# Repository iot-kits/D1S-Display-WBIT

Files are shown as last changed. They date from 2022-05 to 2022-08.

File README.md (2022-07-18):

# D1S-Display-WBIT
These instructions are for the Remote Display kit for users without an IoT Kits weather station. The microcontroller is preprogrammed! IF YOU REPROGRAM IT, THESE INSTRUCTIONS WILL NOT WORK.

## Assembly and Configuration Instructions
### Features:
*	Obtains localized weather information from WeatherBit.io
*	Shows current conditions and daily maximum/minimum
*	Includes wind speed and direction, precipitation type, probability and amount, pressure, temperature, humidity, cloud cover
*	Built in sensor for indoor temperature and humidity
*	User can choose metric and imperial units
*	Precise time provided by National Institute of Standards and Technology (NIST)
*	Displays Universal Coordinated Time (UTC) and your local time.
*	Daylight saving time is automatically determined
*	Almanac for local sunrise and sunset times and moon phase
### What you will need:
1.	Open a free WeatherBit account.
    *	Go to https://www.weatherbit.io/. Click the *Sign up* button, choose a username and password. Write them down! After a few minutes WeatherBit will e-mail a link to confirm your credentials.
    * Log in to WeatherBit. Fill out the form on the *Welcome to WeatherBit* page. The objective is to receive a free Application Programming Interface (API) key. For *API Tier* select “Free (Limited) | $0/mo”. For *API Usage Purpose* choose “Personal Use”. 
    *	WeatherBit will send an e-mail with your API key. You can also find your key on the Dashboard page. Record the API key.
    *	NOTE: YOU CANNOT CONFIGURE THE DISPLAY UNLESS YOU HAVE THE API KEY. It may take a few minutes for WeatherBit to provision your account. Wait for it! 
2.	Find your latitude and longitude. 
    * The weather station uses the location only to localize the weather and find the time zone.
    *	Use https://www.latlong.net/ or a similar service.
    *	The coordinates must be in decimal degrees. For example, the coordinates for the Washington Monument are latitude 39.485279, longitude -77.619972. Two decimal places are adequate: 39.49, -77.62.
    *	Note that north latitude is positive, south latitude is negative, east longitude is positive, west longitude is negative.
3.	Tools needed: 
    *	Soldering iron
    *	Rosin-core solder
    *	Diagonal cutters 
    *	Hot-melt glue gun
    *	Standard USB 5-volt adapter or power supply.
    *	Micro USB cable. Dollar store varieties are acceptable.
 
### Assemble the kit.
**[Click on any thumbnail to enlarge the photograph.]**
1. Have an activated WeatherBit account and API key as described above.
2. Lay out the parts on a safe working surface.
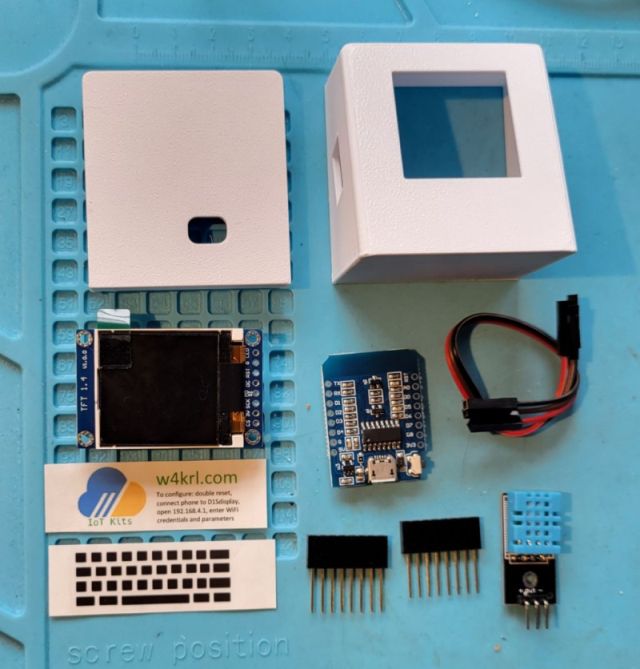
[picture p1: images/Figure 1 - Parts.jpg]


**The next few instructons use the preinstalled pins of the display unit as a fixture to align the D1 Mini assembly. Carefully follow these instructions. You will install and remove connectors several times.**

3. Place the two long-tailed sockets on the display unit pins. You will not need the short tail sockets or header pins if the are provided in the kit.
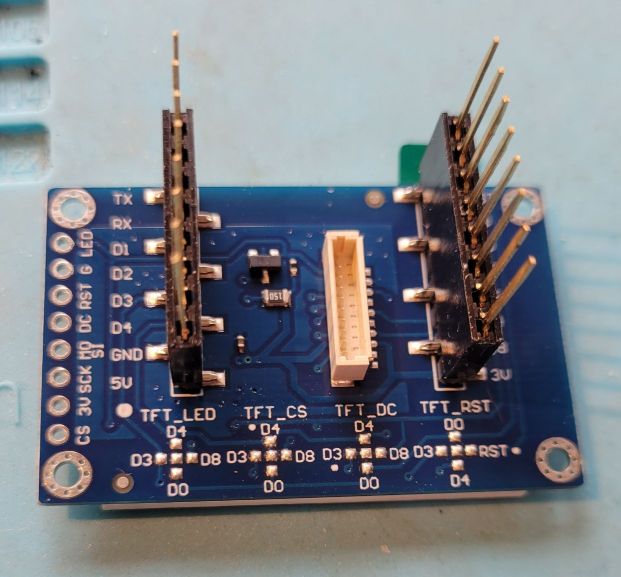
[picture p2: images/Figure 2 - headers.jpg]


4.	Carefully set the D1 Mini onto the pins with the silver case toward the back of the display unit. With the D1 Mini in the correct orientation, you will be soldering on the side with the USB connector.
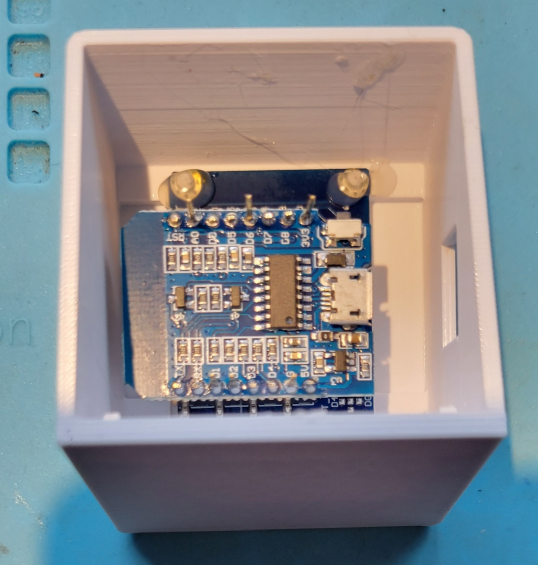
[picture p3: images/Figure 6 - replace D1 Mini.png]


5. Solder each header pin onto the D1 Mini. Carefully inspect your solder joints. Congratulations, you are done soldering.
6. Remove the D1 Mini from the display unit and set aside.
7.	Remove the protective film from the display screen. Place the display into the case with the row of pins RST, A0, D0… toward the top. Engage the holes in the display board with the molded bosses of the case.
8.	While pressing the display into the case to keep it flush, place a dab of hot melt glue on each boss. Hot melt is a good choice because it is removable. You can use other glues at your risk.
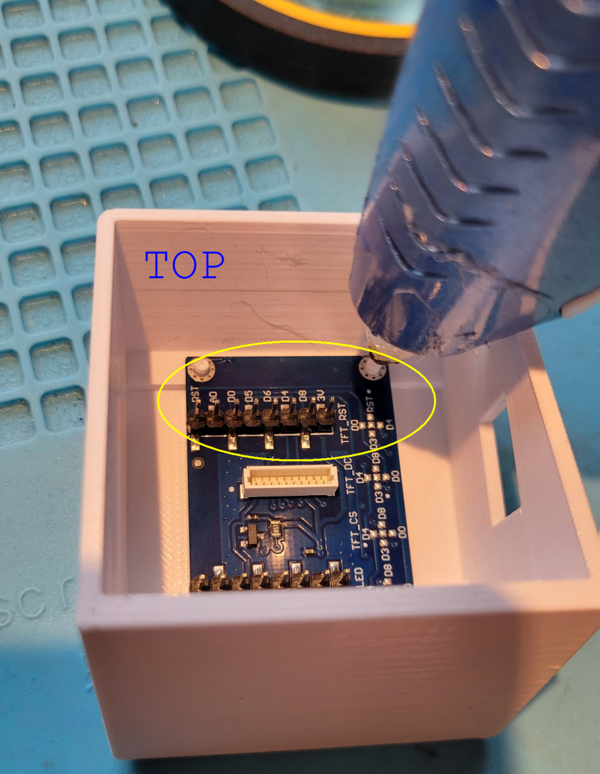
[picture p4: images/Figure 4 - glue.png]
 

9.	Cut off selected leads from the D1 Mini with diagonal cutters.   
   __MAKE SURE YOU UNDERSTAND THIS STEP BEFORE YOU CUT!__  
    *	Cut these pins: RST, D0, D5, D7, D8, TX, RX, D3, D4, 5V.  
    *	**DO NOT CUT THESE PINS:** D6, 3V3, G, D1, D2, A0.
    * NOTE: D6 is used for a DHT11 sensor if supplied. D1 and D2 are for I2C sensors such as the AHT10. A0 is an analog input not used in this kit. 
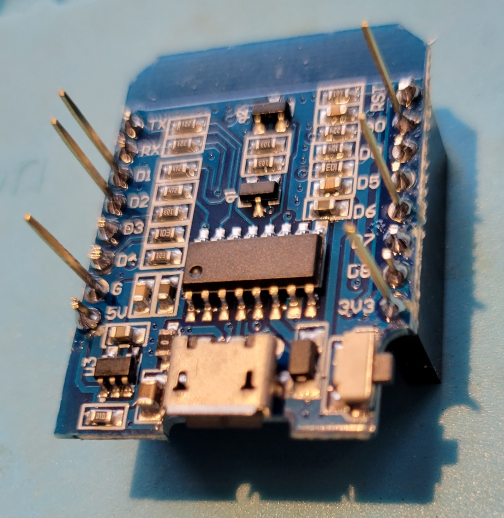
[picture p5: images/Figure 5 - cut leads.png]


10.	Replace the D1 Mini onto the back of the display unit. Observe the orientation so that pin RST of the D1 Mini engages with RST on the display board. All the pins must match.  
  __THE CORRECT ORIENTATION IS CRUCIAL!__  
  __DOUBLE CHECK THAT ALL PINS ARE CORRECTLY MATED WITH RST TO RST AND 5V to 5V, ETC.__  
    * The USB connector will line up with the hole on the side of the case.
11. The kit may be supplied with either a DHT11 or AHT10 temperature/humiidity sensor. The DHT10 has a proprietary bus using three connections. The AHT10 is an I2C device using four pins. Make the connections using the appropriate table in step 12. Place the leads of the jumper cable onto the  sensor pins. Record the color of each wire. The wire colors are different in each kit. As an optional step, you may place a small blob of hot melt glue over the plastic part of the connectors to maintain their orientation if ever removed. Do not place any glue on the metal spring portion of the connectors. Rotate the connector as needed.
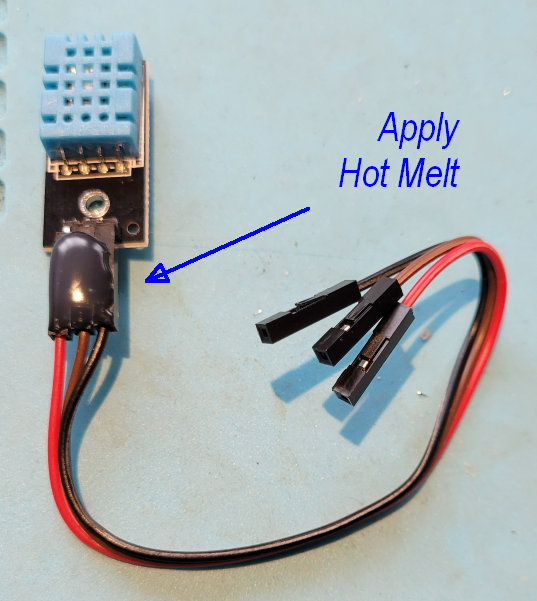
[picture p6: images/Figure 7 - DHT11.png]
  

12. Plug a Micro USB cable onto the D1 Mini USB connector through the opening in the side of the case. Feed the jumper cable through the oval slot in the rear case. Connect the jumper wires to the D1 Mini as shown in the table. If the connector is loose, try rotating it 90 degrees on the pin.

**Connections for DHT11 (if supplied)**
|DHT11 |D1 Mini|Your Wire Color|
|:----:|:-----:|:---:|
| + | 3V3 | |
| OUT  | D6 | |
| - | G | |

**Connections for AHT10 (if supplied)**
|AHT10|D1 Mini|Your Wire Color|
|:----:|:-----:|:---:|
| VIN  | 3V3 | |
| GND  | G | |
| SCL  | D1 | |
| SDA  | D2 | |

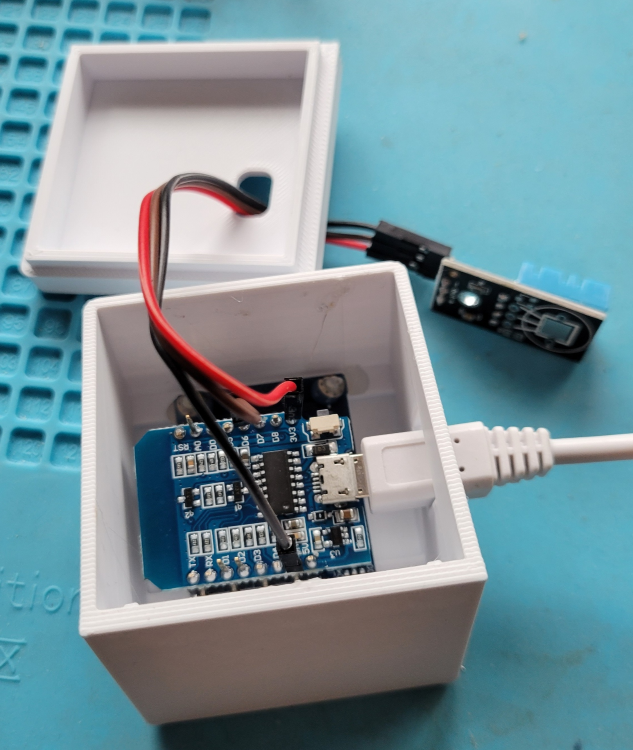
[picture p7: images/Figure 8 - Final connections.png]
 

13. Snap the rear cover onto the case. Place a dab of hot melt glue on the underside of the DHT11 sensor and place it on the upper right of the case cover.
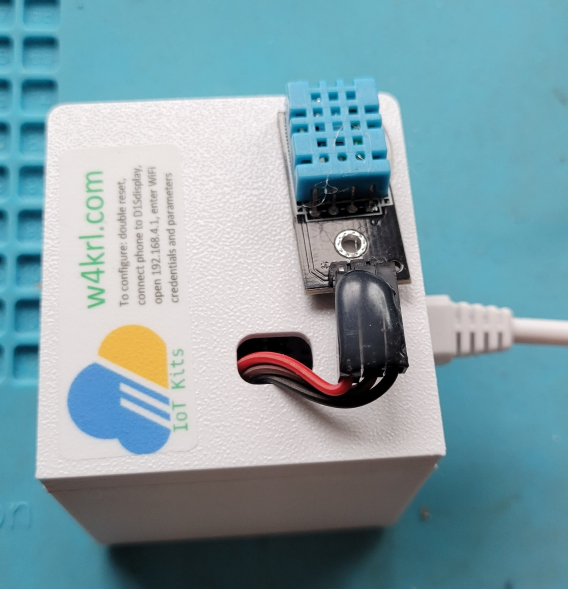
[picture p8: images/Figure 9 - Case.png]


14. Apply the nameplate on the rear of the case. The step is optional: Apply the decorative keyboard label under the display.
15. The assembly is complete. The next step is to configure the soaftware.

### Software Configuration
These instructions are for a cell phone with Wi-Fi capability. The same method could be used with a Wi Fi connected computer. 
You must be familiar with how to open the Wi-Fi connection settings on your phone, how to open your phone’s web browser, and how to enter an URL into the browser’s address bar.
This procedure will temporarily turn the weather display into a Wi-Fi access point. You will connect your cell phone to the display unit’s Wi-Fi signal. Then use your cell phone’s Internet browser to open a web page hosted by the weather display. After you enter the configuration information into the web page, the weather display will connect to your Wi-Fi network and begin normal operation.  
**Do not connect the display to a power supply until instructed to do so.**
You will need ALL the accounts and information noted in the section "What you will need" above. Do not proceed unless you have ALL this information. 
1.	Have all the configuration information at hand ready to enter:  
    *	Your Wi-Fi name (SSID) and password
    *	Your WeatherBit API key
    *	Your latitude and longitude in decimal degrees
2.	Plug the USB cable into a standard 5-volt adapter or power supply. The display will show a splash screen then brief instructions for configuring the unit will appear.
3.	Open your phone’s Wi-Fi connection settings. Turn off auoto reconnect on your current Wi-Fi connection. After a brief delay *D1Sdisplay* will appear in the list of available networks. Select it and wait for your phone to connect. You may safely ignore any warning that no Internet is available.
4.	Open your phone’s browser. Enter **192.168.4.1** into the address bar. A web page will appear.
5.	Enter the following information:  
    * Your Wi-Fi SSID (you may select this from the available networks shown at the top of the web page)
    *	Your Wi-Fi password
    * Your latitude in decimal degrees. Positive for north latitudes, negative for south latitudes.
    *	Your longitude in decimal degrees. Positive for east longitudes, negative for west longitudes.
    *	Select Imperial or Metric units.
    *	~~Check the Show clock box if you wish to have the unit display local and UTC times.~~
    *	Select the duration of each display screen: 5, 7, 10, 12, or 15 seconds. Recommendation is 7 or 10 seconds.
6.	The weather display will save the configuration data, connect to your WI-Fi and begin downloading time and weather information.  This may take a minute or so.
7.	Go back to your phone settings and turn on auto reconnect for your regular Wi-Fi connection.
8.	If you ever need to change any parameter, press the reset button on the D1 Mini twice in succession. You may have to do this a few times. The unit goes into configuration mode when the blue LED on the D1 Mini turns on and the configuration reminder screen appears.
9. See [Display Descriptions](https://github.com/iot-kits/D1S-Display-WBIT/blob/main/DISPLAY_DESCRIPTIONS.md) for more information.

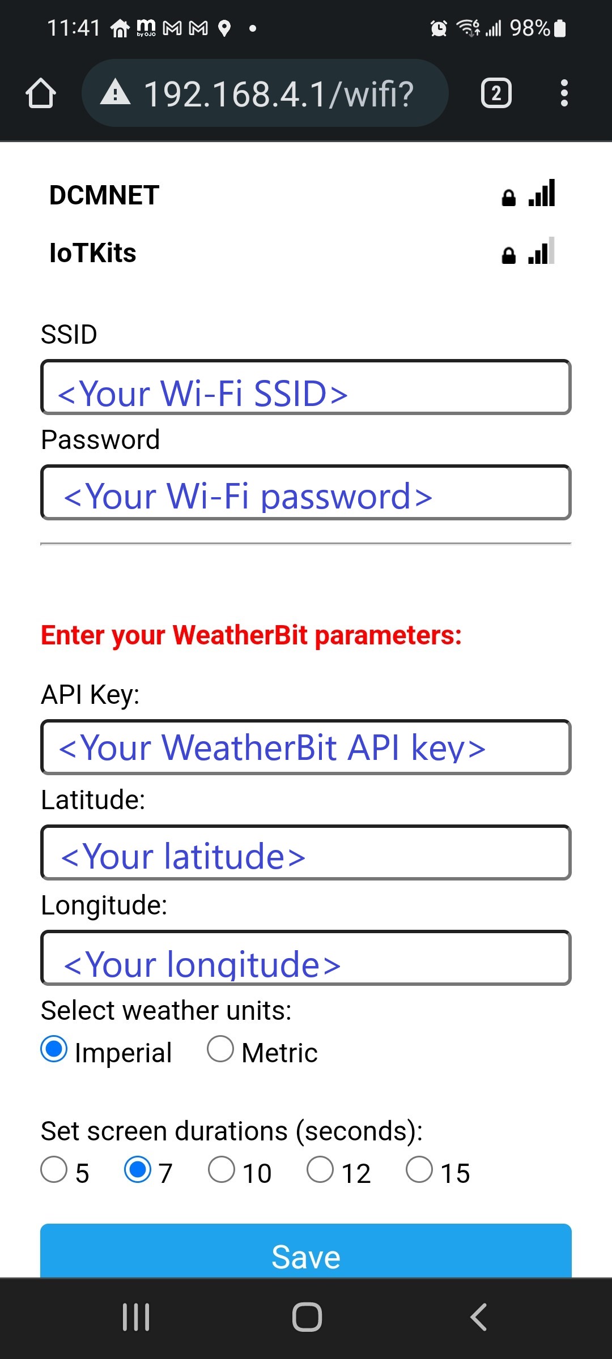
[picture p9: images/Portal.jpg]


## Other Display Screens
|Click to enlarge| | | |
|:----:|:----:|:----:|:----:|
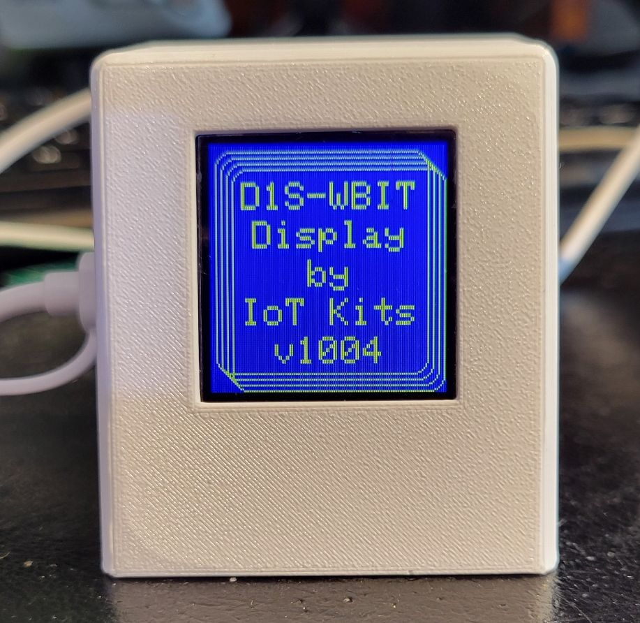
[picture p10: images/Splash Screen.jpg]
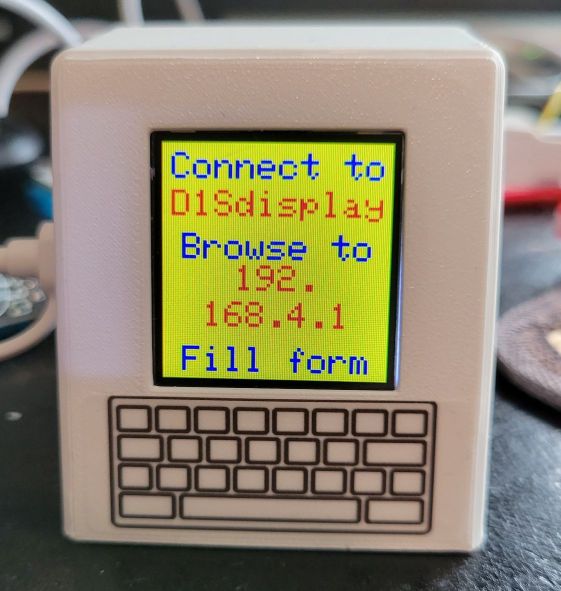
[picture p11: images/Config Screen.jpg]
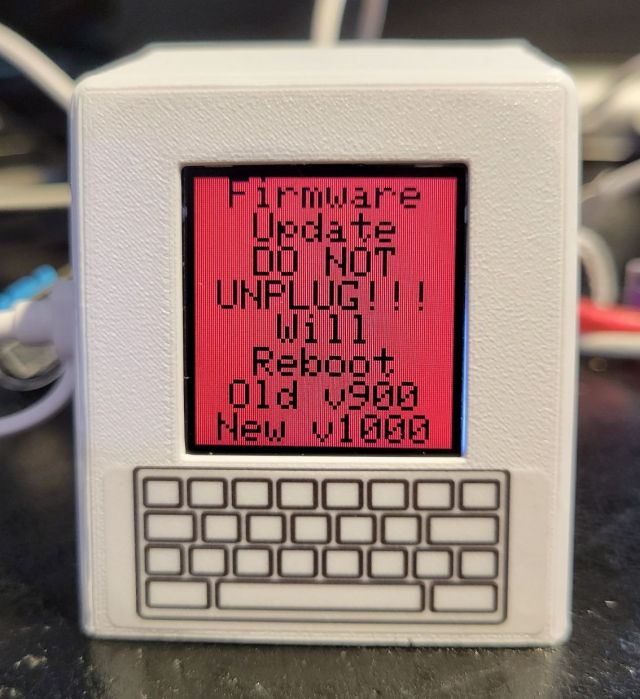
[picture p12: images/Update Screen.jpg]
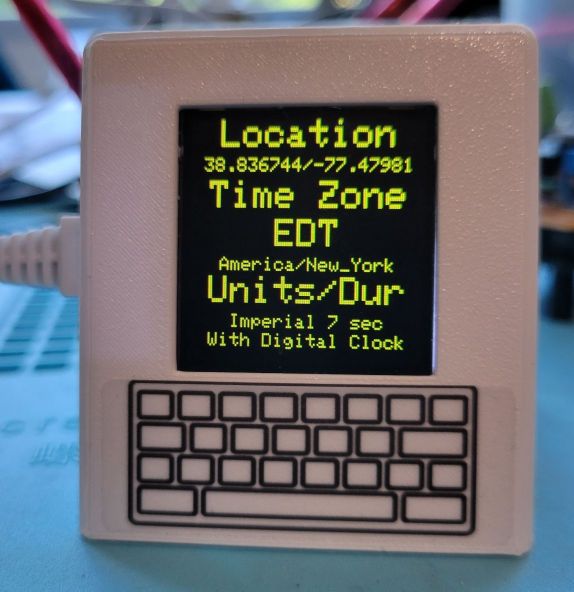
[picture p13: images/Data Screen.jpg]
|||||
|Splash Screen|Configuration Screen|Firmware Update Screen| Data Screen |
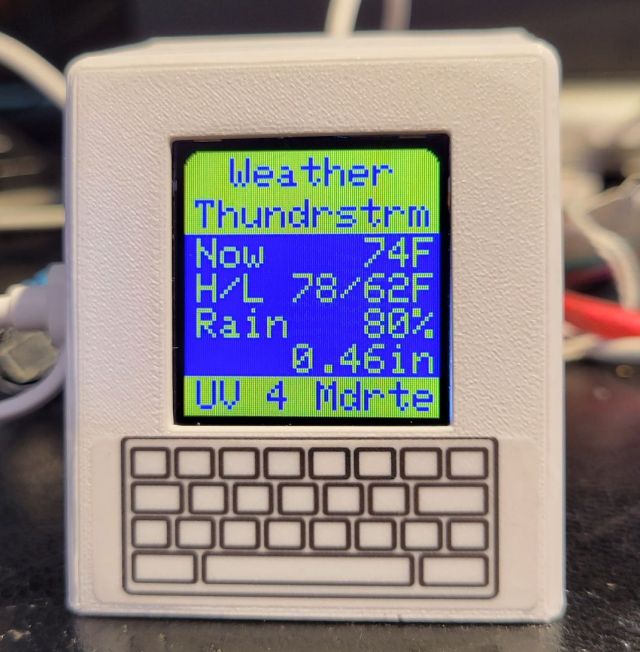
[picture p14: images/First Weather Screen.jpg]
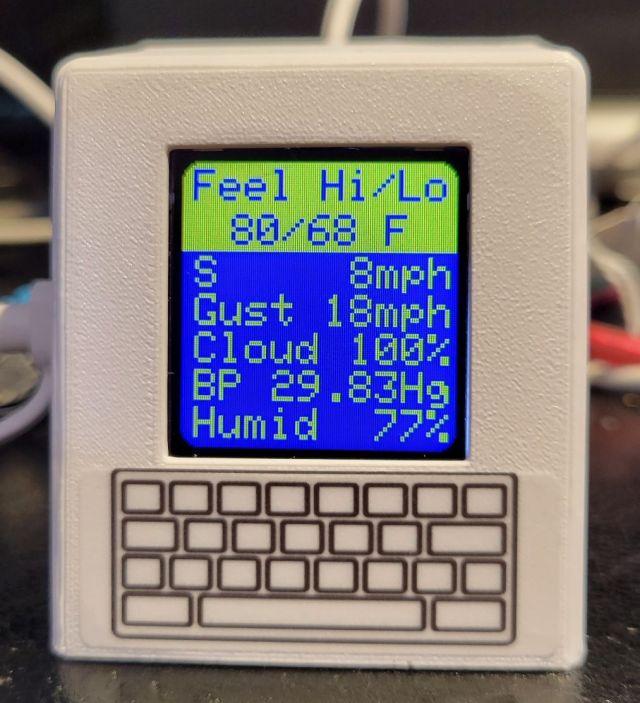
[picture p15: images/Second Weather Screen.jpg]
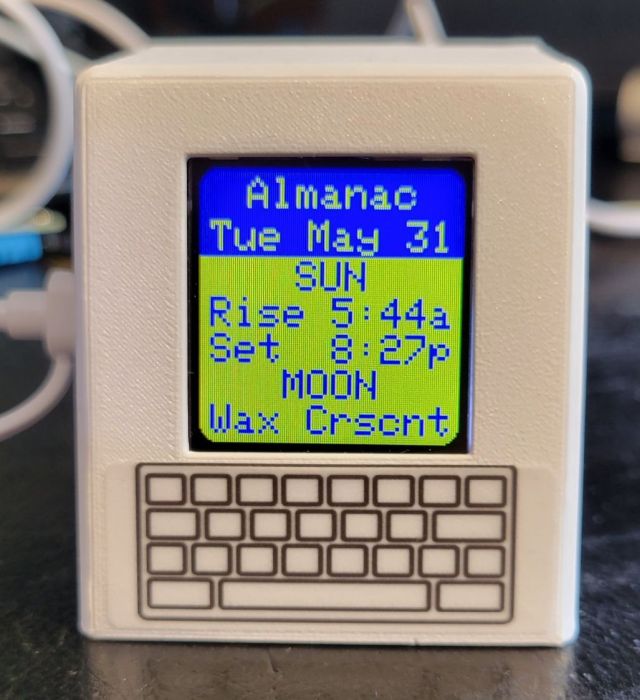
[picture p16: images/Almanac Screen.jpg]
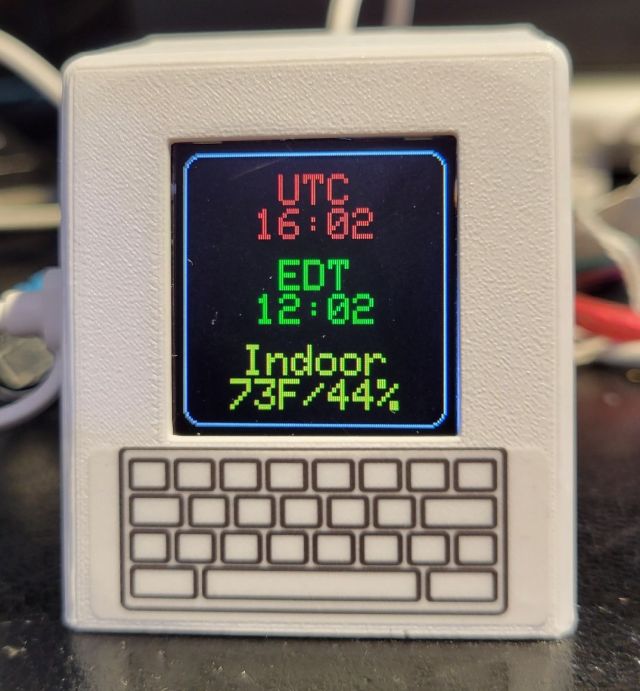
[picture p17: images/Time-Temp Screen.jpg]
|||||
|First Weather Screen|Second Weather Screen|Almanac Screen| Time & Temperature Screen |

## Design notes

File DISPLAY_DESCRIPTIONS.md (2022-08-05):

# D1S-Display-WBIT

## Descriptions of Displays

|Screen |Photo (click to enlarge)|Description|
|----|:----:|----|
|**Splash Screen**|| <ul><li>Abbreviated firmware name </li> <li>Firmware version</li></ul> |
|**Data Screen**|| <ul><li> Location latitude / logitude </li><li> Time zone abbreviation and Olson name </li> <li>Units (metric/imperial) and screen duration in seconds </li> <li>Other display information</li></ul>|
|**Weather #1** | | <ul><li>Brief weather condition forecast – see list of weather conditions </li> <li>Current temperature </li> <li>Temperature forecast: Daytime High / Nighttime low  </li> <li>Probability of precipitation (rain or snow) forecast </li> <li>Accumulated amount of rain or snow forecast </li> <li>Ultraviolet Index maximum forecast – background color changes with level – see list of UV Index</li></ul>| 
|**Weather #2**| | <ul><li>Feels like high and low temperatures </li> <li>Wind direction and speed</li> <li>Wind gust speed </li> <li>Cloud cover in percent </li> <li>Barometric Pressure at Sea Level </li> <li>Relative Humidity in percent</li></ul>| 
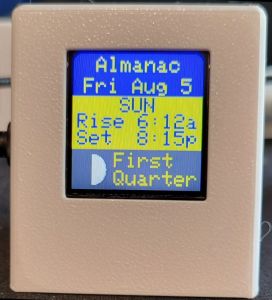
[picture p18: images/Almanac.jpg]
|**Almanac**| | <ul><li>Day and date</li> <li>Sun Rise local time (am)</li> <li>Sun Set local time (pm) </li> <li>Moon Phase Graphic & Text</li></ul> |
|**Digital Clock**| | <ul><li>Universal Coordinated Time (UTC) with seconds</li> <li>Local Time (24-hour) </li> <li>Indoor Temperature & Humidity</li></ul>| 
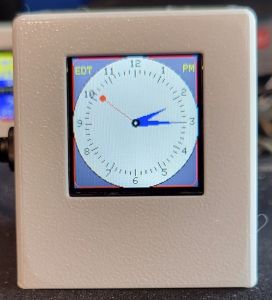
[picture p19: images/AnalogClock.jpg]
|**Analog Clock**| | <ul><li>Local Time with seconds on a 12-hour dial</li><li>Local Timezone Abbreviation</li><li>AM/PM indication</li><li>Indoor Temperature & Humidity if the Digital Clock is not selected</li></ul> | 
|**Configuration**|| <ul><li>Brief instructions for software configuration </li> <li>SSID is D1Sdisplay </li> <li>Portal URL is 192.168.4.1 </li></ul>|
|**Firmware Update**| | <ul><li>Screen appears when Iot Kits has published a firmware update </li> <li>Do not turn off the unit during update </li></ul>|

## Time and Weather Information
The display shows time from the [National Institute of Standards and Technology (NIST)](https://en.wikipedia.org/wiki/National_Institute_of_Standards_and_Technology). The time is automatically adjusted for standard and daylight saving for the [Olson time zone](https://en.wikipedia.org/wiki/Tz_database) based on the display's latitude and longitude. 

Weather information is provided by [weatherbit.io](https://www.weatherbit.io/). Conditions are localized with the display's latitude and longitude. During the day, current conditions are updated every 10 minutes. The forecast is updated every hour. Between midnight and 7 am the updates occur every hour for current conditions and every two hours for the forecast.

## List of Weather Conditions
Reference: [www.weatherbit.io/api/codes](https://www.weatherbit.io/api/codes)

Note that these weather observation codes are very similar to those used by [Open Weather Map](https://openweathermap.org/weather-conditions)

|Screen Display|Condition|WeatherBit code|
|:---:|:---:|----|
|Thundrstrm |Thunderstorm  | 200 - 233 |
|Lte Drzzle |Light Drizzle | 300|
|Drizzle |Drizzle | 301, 310 - 321 |
|Hvy Drzzle |Heavy Drizzle | 302|
|Light Rain |Light Rain | 500|
|Modrt Rain |Moderate rain | 501|
|Heavy Rain |Heavy Rain | 502|
|Extrm Rain |Extreme Rain  | 503, 504 |
|Frzng Rain |Freezing Rain | 511|
|Rain Shwrs |Rain Showers  | 520 - 531 |
|Light Snow |Light Snow | 600, 620 |
|Heavy Snow |Heavy Snow | 601, 602, 622 |
|Rain&Snow  |Mixed Rain and Snow | 610, 615, 616|
|Sleet |Sleet | 611, 613|
|Snow Showr |Snow Shower | 621|
|Flurries |Flurries | 623|
|Mist |Mist | 700, 701|
|Smoke |Smoke | 711|
|Haze |Haze | 721|
|Sand/Dust  |Sand/Dust | 731|
|Frzng Fog  |Freezing Fog  | 751|
|Dust |Dust | 761|
|Clear Sky  |Clear Sky | 800|
|Few Clouds |Few Clouds | 801|
|Sctrd Clds |Scattered Clouds | 802|
|Brkn Clds  |Broken Clouds | 803|
|Overcast |Overcast Clouds | 804|
|Ukn Precip |Unknown Precipitation | 900|
|Undefined  |Undefined | Undefined|

## Moon Phases

|Screen Display|Name|Days|
|:----:|:----:|:----:|
|New |New |0 - 1|
|Wax Crscnt| Waxing Crescent| 2 - 6|
|First Qrtr| First Quarter  | 7 - 8|
|Wax Gibous| Waxing Gibbous | 9 - 13|
|Full | Full |14 - 16|
|Wan Gibous| Waning Gibbous |17 - 21|
|Last Qtr  | Last Quarter |22 - 23|
|Wan Crscnt| Waning Crescent|24 - 28|
|New | New |29|
* The moon goes through a 29.53-day cycle.
* Waxing: The lighted portion is growing. 
* Waning: The lighted portion is shrinking.
* Crescent: The lighted portion is less than half. 
* Gibbous: The lighted portion is more than half.

## Ultraviolet Index
The UV Index is an indication of how quickly your skin will burn when outdoors.
|Screen Display|Risk|Color|Protection|
|:----:|:----:|:----:|---|
|0, 1, 2</br>**Low** |Low |Green |No protection needed. You can safely stay outside using minimal sun protection.|
|3, 4, 5</br>**Mdrte** |Moderate |Yellow|Protection needed. Seek shade during late morning through mid-afternoon. When outside, generously apply broad-spectrum SPF-15 or higher sunscreen on exposed skin, and wear protective clothing, a wide-brimmed hat, and sunglasses.|
|6, 7</br>**High** |High|Orange|Protection against skin and eye damage is needed. Reduce time in the sun between 10 a.m. and 4 p.m. If outdoors, seek shade and wear sun-protective clothing, a wide-brimmed hat, and UV-blocking sunglasses. Generously apply broad spectrum SPF 15+ sunscreen every 1.5 hours, even on cloudy days, and after swimming or sweating. Bright surfaces, such as sand, water, and snow, will increase UV exposure.|
|8, 9, 10</br>**VryHi**  |Very High  |Red |Extra protection needed. Be careful outside, especially during late morning through mid-afternoon. Seek shade and wear protective clothing, a wide-brimmed hat, and sunglasses, and generously apply a minimum of  SPF-15, broad-spectrum sunscreen on exposed skin.|
|11 & up</br>**Xtrm**|Extreme |Purple|Take all precautions because unprotected skin and eyes can burn in minutes. Try to avoid sun exposure between 10 a.m. and 4 p.m. If outdoors, seek shade and wear sun-protective clothing, a wide-brimmed hat, and UV-blocking sunglasses. Generously apply broad spectrum SPF 15+ sunscreen every 1.5 hours, even on cloudy days, and after swimming or sweating. Bright surfaces, such as sand, water, and snow, will increase UV exposure.|

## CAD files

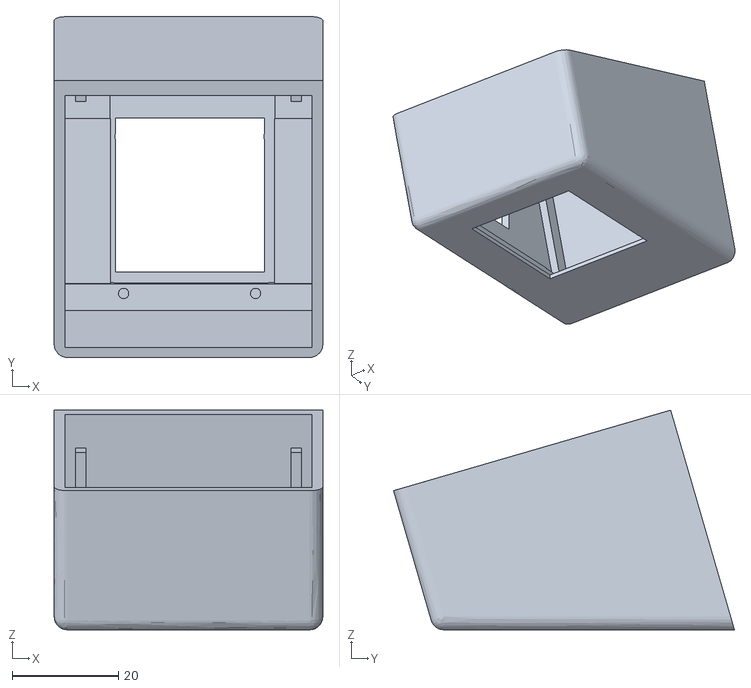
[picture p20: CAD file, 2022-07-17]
3D_Printer_Files/D1 Mini Display Front v3.stl
50.5 x 64.1 x 41.3

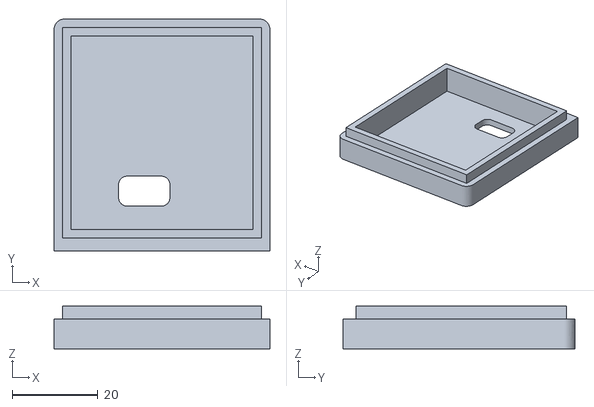
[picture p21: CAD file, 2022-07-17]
3D_Printer_Files/D1S Display Cover v3.stl
50.5 x 54.3 x 10.0

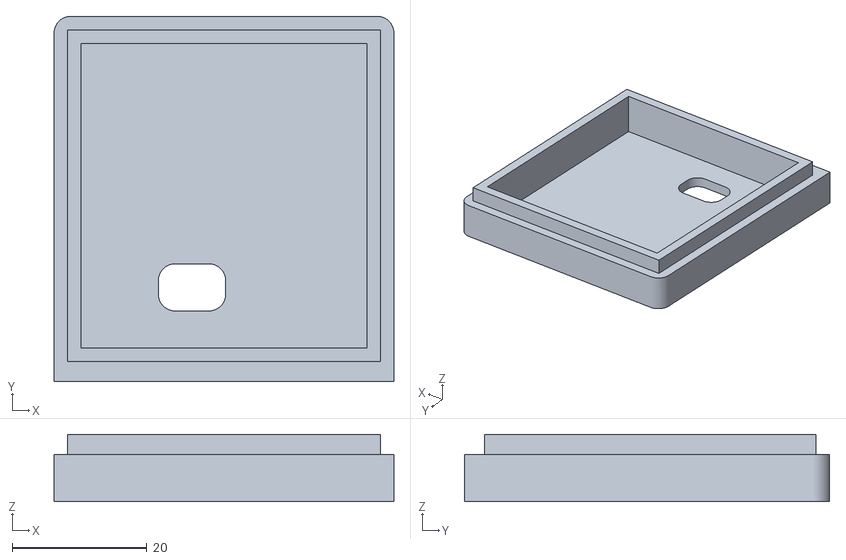
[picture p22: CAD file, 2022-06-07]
3D_Printer_Files/D1 Mini Display Case Rear.stl
50.5 x 54.3 x 10.0

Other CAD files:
3D_Printer_Files/D1 Mini Display Front Case.stl

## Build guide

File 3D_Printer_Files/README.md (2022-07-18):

Use version v3 stl files. Files without version numbers are for reference.
* Front case was thickened left and right of screen opening to reduce light transmission
* Front case opening for USB connector lengthened
* Cover opening lengthened to allow passage of four Dupont connectors for I2C sensors

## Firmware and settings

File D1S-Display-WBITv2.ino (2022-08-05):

// D1S-Display-WBIT
// this version accomodates modified and unmodified TFT screens
// it must be compiled as one or the other
// unmarked version has CS = D4
// version v2 with TFT_MOD CS = D0
// both versions autodetect AHT10 and DHT11 sensors

const int FW_VERSION = 1006;

//! uncomment to compile for modified screen
#define TFT_MOD

//! uncomment this line for serial output
//#define DEBUG

// 1006 - 2022-08-02 extensive mods
//                   revised ota.h
//                   graphic moon phase
//                   autodetect AHT10 & DHT11
//                   moved WFM to setup()
//                   revised dataScreen
//                   added config options for clocks
// 1005 - 2022-07-20 show SLP in mb always
//      - 2022-07-19 elliptical moon face on almanac
//      - 2022-07-14 sensor detection
//      - rearranged drd
// 1004 - 2020-06-10 calculate moon phase, added HTU21D
// 1003 - 2022-05-28 detect DHT11 in Digital Clock frame,
//                   remove clock checkbox from WFM,
//                   remove analog clock frame code
// 1002 - 2022-05-27 Corrected conversions, replaced vis with bp second wx frame
// 1001 - 2022-05-23 SAVE!!! WFM working with beta version

// Displays local time and weather exclusively from WeatherBit.io
/* Configured using WiFiManager captive portal at 192.168.4.1
 ? Data Needed:
 *   Wi-Fi credentials (SSID & Password)
 *   WeatherBit.io API key
 *   Latitude & longitude decimal degrees
  */

/*_____________________________________________________________________________
   Copyright(c) 2018 - 2022 Karl Berger dba IoT Kits https://w4krl.com

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
   THE SOFTWARE IS PROVIDED "AS IS", WITHOUT WARRANTY OF ANY KIND, EXPRESS OR
   IMPLIED, INCLUDING BUT NOT LIMITED TO THE WARRANTIES OF MERCHANTABILITY,
   FITNESS FOR A PARTICULAR PURPOSE AND NONINFRINGEMENT. IN NO EVENT SHALL THE
   AUTHORS OR COPYRIGHT HOLDERS BE LIABLE FOR ANY CLAIM, DAMAGES OR OTHER
   LIABILITY, WHETHER IN AN ACTION OF CONTRACT, TORT OR OTHERWISE, ARISING FROM,
   OUT OF OR IN CONNECTION WITH THE SOFTWARE OR THE USE OR OTHER DEALINGS IN THE
   SOFTWARE.
   _____________________________________________________________________________
*/

/*
******************************************************
*************** INCLUDES & MACROS*********************
******************************************************
*/

// For general sketch
#include <Arduino.h>           // PlatformIO
#include <Wire.h>              // [builtin]
#include <ESP8266WiFi.h>       // [builtin]
#include <ArduinoJson.h>       // [manager] v6.19.4 Benoit Blancho https://arduinojson.org/
#include <ESP8266HTTPClient.h> // [builtin] http

// For Wemos TFT 1.4 display shield
#include <Adafruit_GFX.h>    // [manager] v1.11.3 Core graphics library
#include <Adafruit_ST7735.h> // [manager] v1.9.3 Controller chip
#include <SPI.h>             // [builtin]
#include "colors.h"          // custom frame colors

// For indoor sensors
#include <Adafruit_Sensor.h> // v1.1.5 may not be needed
#include <DHT.h>             // v1.4.4 DHT11
#include <Adafruit_AHTX0.h>  // v2.0.1 AHT10

// Time functions by Rop Gonggrijp https://github.com/ropg/ezTime
#include <ezTime.h> // [manager] v0.8.3 NTP & timezone

// For HTTPS OTA
#ifdef TFT_MOD
const String FW_FILENAME = "D1S-Display-WBITv2";
#else
const String FW_FILENAME = "D1S-Display-WBIT";
#endif
#include <ESP8266HTTPClient.h>       // [builtin] http
#include <WiFiClientSecureBearSSL.h> // [builtin] https
#include <ESP8266httpUpdate.h>       // [builtin] OTA
#include "ota.h"                     // server paths

// For WiFiManager library
// in platformio.ini add   lib_deps = https://github.com/tzapu/WiFiManager.git
#include <LittleFS.h>            // [builtin] LittleFS File System
#include <DNSServer.h>           // [builtin] For webserver
#include <ESP8266WebServer.h>    // [builtin] For webserver
#include <WiFiManager.h>         // [manager] v2.0.11-beta+sha.9c7fed4 https://github.com/tzapu/WiFiManager
#include <DoubleResetDetector.h> // [manager] v1.0.3 Stephen Denne https://github.com/datacute/DoubleResetDetector

#ifdef DEBUG
#define DEBUG_PRINT(x) Serial.print(x)
#define DEBUG_PRINTLN(x) Serial.println(x)
#else
#define DEBUG_PRINT(x)
#define DEBUG_PRINTLN(x)
#endif

//  bool resetFS = true;  //! Erase Little FS
bool resetFS = false; //! Do not erase Little FS

/*
******************************************************
******************* DEFAULTS *************************
******************************************************
*/
const char AP_PORTAL_NAME[] = "D1Sdisplay";               //! must be <11 characters
const String CONFIG_FILENAME = "/config.json";            // LittleFS filename
const int USB_LEFT = 0;                                   // display orientation codes
const int USB_DOWN = 1;                                   // location of USB port
const int USB_RIGHT = 2;                                  // as viewed from
const int USB_UP = 3;                                     // the front of the display
const int FRAME_ORIENTATION = USB_LEFT;                   // for IoT Kits case
const String WX_SERVER = "http://api.weatherbit.io/v2.0"; // weather api server
const String WX_FORECAST = "forecast/daily";              // forecast API
const String WX_CURRENT = "current";                      // current conditions API
const String WX_DAYS = "1";                               // number of days in forecast
const int WX_CURRENT_SHORT_INTERVAL = 10;                 // intervals are in minutes
const int WX_CURRENT_LONG_INTERVAL = 60;                  // WeatherBit limit 500 requests per day ( 2 min 53 sec )
const int WX_FORECAST_SHORT_INTERVAL = 30;                // minutes between forecast in daytime
const int WX_FORECAST_LONG_INTERVAL = 120;                // minutes between forecasts at night
const int DRD_TIMEOUT = 2;                                // seconds between resets
const int DRD_ADDRESS = 32;                               // avoid OTA area

/*
******************************************************
***************** DEVICE CONNECTIONS *****************
******************************************************
*/
//  5V - not used
// 3V3 - power to DHT11 and I2C devices
// GND - return for sensors
//  TX - GPIO 1 not used
//  D4 - GPIO 2 LED_BUILTIN
//  RX - GPIO 3 not used
//  D2 - GPIO 4 I2C SDA
//  D1 - GPIO 5 I2C SCL
//  A0 - ADC not used
//! TFT = WEMOS 1.4 shield connections
const int TFT_RST = 0; // use -1 according to Wemos
const int TFT_DC = D3; // GPIO  0
const int DHTPIN = D6; // GPIO 12 DHT11 humidty/temperature sensor
#define TFT_MOSI D7    // GPIO 13
#define TFT_SCK D5     // GPIO 14
#define SS D8          // GPIO 15 not used
#define WAKE D0        // GPIO 16 not used
#define TFT_LED NC;    // Not used
//! Mod to screen moves CS from D4 to D0 to avoid LED flash
//! Used on kits starting August 2022
#ifdef TFT_MOD
const int TFT_CS = D0; // GPIO 16 MODIFIED TFT
#warning !!!!! COMPILING FOR TFT MOD !!!!!
#else
const int TFT_CS = D4; // GPIO  2 Builtin LED
#warning !!!!! COMPILING FOR STANDARD TFT !!!!!
#endif

/*
******************************************************
**************** INSTANTIATE DEVICES *****************
******************************************************
*/
Adafruit_ST7735 tft = Adafruit_ST7735(TFT_CS, TFT_DC, TFT_RST); // WEMOS TFT 1.4 Display
DHT dht(DHTPIN, DHT11);                                         // Temperature/Humidity Sensor
Adafruit_AHTX0 aht;                                             // Temperature/Humidity Sensor
Adafruit_Sensor *aht_humidity, *aht_temp;                       // Unified sensor library
WiFiClient client;                                              // Wi-Fi connection
Timezone myTZ;                                                  // Local timezone
DoubleResetDetector drd(DRD_TIMEOUT, DRD_ADDRESS);              // Avoid conflict with RTC memory
WiFiManager wm;                                                 // Beta version of WiFiManager
WiFiManagerParameter custom_unit;                               // Weather units param
WiFiManagerParameter custom_duration;                           // Screen duration param

/*
******************************************************
******************* GLOBALS **************************
******************************************************
*/
// structure to hold weather data & calculated values
// all are from "forecast" api unless marked "current"
struct
{
  unsigned int wxCode;     // weather code
  String timezone;         //! Olson timezone from current
  float tempC;             //! temperature (°C) from current
  float tempCdayHigh;      // from 7 am to 7 pm
  float tempCnightLow;     // from 7 pm to 7 am
  float tempCfeelHigh;     // apparent high
  float tempCfeelLow;      // apparent low
  float tempCdew;          // dew point (°C)
  unsigned int humidity;   //! relative humidity (%) from current
  float slp;               //! sea level pressure (hPa) from current
  unsigned long sunRise;   // sunrise (unix time UTC)
  unsigned long sunSet;    // sunset (unix time UTC)
  float lunation;          // 0 = New, 0.25 = 1st Q, 0.5 = Full
  float windSpeed;         // wind speed (m/s)
  float windGust;          // wind gust (m/s)
  String windDirection;    // abbreviation like ENE
  unsigned int clouds;     // clouds (%)
  float visibility;        // km
  unsigned int precipProb; // probablility of precipitation (%)
  float rain;              // equivalent liquid precip (mm)
  float snowDepth;         // accumulated snow depth (mm)
  int tzOffset;            // minutes from UTC (negative is west)
  float uvForecast;        // UV index (0-11+)
  float uvCurrent;         // current UV Index
} wx;

struct
{
  float tempC;
  float humid;
} indoor;

bool metricUnits = false;
bool digitalClock = false;
bool analogClock = false;
int screenDuration = 5;
const int SENSOR_NONE = 0;
const int SENSOR_DHT11 = 1;
const int SENSOR_AHT10 = 2;
const int SENSOR_HTU21D = 3;
int sensorType = SENSOR_NONE; // initialize for none

//! ********* WIFI MANAGER CONFIG PARAMS ***************
// these char arrays hold the user's response to each parameter
const int TZ_SIZE = 40;        // Olson timezone string
const int API_SIZE = 40;       // WeatherBit API key
const int GEO_SIZE = 12;       // Lat/Lon
bool shouldSaveConfig = false; // WFM callback

//! Initialize WiFiManager parameters
char wm_wx_api[API_SIZE] = "";       // get free account at https://www.weatherbit.io/
char wm_wx_lat[GEO_SIZE] = "38.89";  // Washington Monument
char wm_wx_lon[GEO_SIZE] = "-77.04"; // 2 decimals are sufficient
char wm_wx_dlc[2] = "";              // digital clock - none or D
char wm_wx_alc[2] = "";              // analog clock - none or A
char wm_wx_unt[2] = "I";             // Imperial units or M
char wm_wx_dur[3] = "5";             // show screens for 5 seconds

//! *********** WEMOS TFT 1.4 SETTINGS ******************
const int SCREEN_W = 128;           // width in pixels
const int SCREEN_H = 128;           // height in pixels
const int SCREEN_W2 = SCREEN_W / 2; // half width
const int SCREEN_H2 = SCREEN_H / 2; // half height
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
void loop()
{
  static bool shouldUpdateCurrent = true;
  static bool shouldUpdateForecast = true;

  //  drd.loop(); // process user reset request
  events(); // ezTime events - autoconnect to NTP server

  if (secondChanged()) // ezTime function
  {
    updateFrame();
  }
  // set and check weather update intervals every minute
  int currentInterval = WX_CURRENT_SHORT_INTERVAL;
  int forecastInterval = WX_FORECAST_SHORT_INTERVAL;
  static int oldMinute = 0;
  if (oldMinute != minute())
  {
    oldMinute = minute();
    {
      if (hour() < 7) // long intervals between midnight and 7 am
      {
        currentInterval = WX_CURRENT_LONG_INTERVAL;
        forecastInterval = WX_FORECAST_LONG_INTERVAL;
      }
      // check if this interval needs current WX update
      if (minute() % currentInterval == 0)
      {
        if (shouldUpdateCurrent)
        {
          getWXcurrent();
          shouldUpdateCurrent = false;
        }
      }
      else
      {
        shouldUpdateCurrent = true;
      }
      //   check if this interval needs WX forecast update
      if ((60 * hour() + minute()) % forecastInterval == 0)
      {
        if (shouldUpdateForecast)
        {
          getWXforecast();
          shouldUpdateForecast = false;
        }
      }
      else
      {
        shouldUpdateForecast = true;
      }
    }
  }
} // loop()

/*
******************************************************
************* WIFIMANAGER CALLBACKS ******************
******************************************************
*/
void configModeCallback(WiFiManager *wm)
{
  digitalWrite(LED_BUILTIN, LOW); // turn D1 Mini LED ON
  DEBUG_PRINTLN(F("[CALLBACK] config mode"));
  wfmInstructionScreen(); // shows a reminder on the TFT display
} // configModeCallback()

// callback when there is need to save config
void saveConfigCallback()
{
  DEBUG_PRINTLN("[CALLBACK] save config");
  shouldSaveConfig = true;
} // saveConfigCallback()

void saveCustomParamCallback()
{
  DEBUG_PRINTLN("[CALLBACK] saveCustomParamCallback");
  // process custom html parameters
  String unit = getParam("customUnitID");
  strcpy(wm_wx_unt, getParam("customUnitID").c_str());
  String duration = getParam("customDurationID");
  strcpy(wm_wx_dur, duration.c_str());
  DEBUG_PRINTLN("PARAM customUnitID = " + unit);
  DEBUG_PRINTLN("PARAM customDurationID = " + duration);
  DEBUG_PRINT("Units: ");
  metricUnits = (unit == "M") ? true : false;
  screenDuration = duration.toInt();
  DEBUG_PRINT("Duration: ");
  DEBUG_PRINTLN(screenDuration);
} // saveCustomParamCallback()

void saveParamCallback()
{
  DEBUG_PRINTLN("[CALLBACK] saveParamCallback fired");
  DEBUG_PRINTLN("PARAM customfieldid = " + getParam("customfieldid"));
}

String getParam(String name)
{
  DEBUG_PRINTLN("[CALLBACK] getParam");
  // read parameter from server, for custom hmtl input
  String value;
  if (wm.server->hasArg(name))
  {
    value = wm.server->arg(name);
  }
  DEBUG_PRINT("PARAM value = ");
  DEBUG_PRINTLN(value);
  return value;
} // getParam(String name)

/*
******************************************************
*********** WiFi Manager Functions *******************
******************************************************
*/
void readConfig()
{
  // LittleFS = Serial Peripheral Inteface Flash File System
  // https://arduino-esp8266.readthedocs.io/en/3.0.2/filesystem.html
  // from wifiManager example AutoConnectWithFSParameters
  // https://github.com/tzapu/WiFiManager/tree/master/examples/Parameters/SPIFFS/AutoConnectWithFSParameters
  if (LittleFS.begin())
  {
    DEBUG_PRINTLN("Mounted file system");
    if (LittleFS.exists(CONFIG_FILENAME))
    {
      // file exists - read and copy to globals
      File configFile = LittleFS.open(CONFIG_FILENAME, "r");
      if (configFile)
      {
        DEBUG_PRINTLN("Opened config file");
        size_t size = configFile.size();
        // Allocate a buffer to store contents of the file.
        std::unique_ptr<char[]> buf(new char[size]); // was + 1

        configFile.readBytes(buf.get(), size);

        DynamicJsonDocument json(1024);

        auto deserializeError = deserializeJson(json, buf.get());
        serializeJson(json, Serial);
        if (!deserializeError)
        {
          // copy from json to global strings
          strcpy(wm_wx_api, json["wx_api"]);
          strcpy(wm_wx_lat, json["wx_lat"]);
          strcpy(wm_wx_lon, json["wx_lon"]);
          strcpy(wm_wx_unt, json["wx_met"]);
          strcpy(wm_wx_dlc, json["wx_dlc"]);
          strcpy(wm_wx_alc, json["wx_alc"]);
          strcpy(wm_wx_dur, json["wx_dur"]);

          digitalClock = (strcmp(wm_wx_dlc, "D") == 0) ? true : false;
          analogClock = (strcmp(wm_wx_alc, "A") == 0) ? true : false;
          metricUnits = (strcmp(wm_wx_unt, "M") == 0) ? true : false;
          screenDuration = atoi(wm_wx_dur);

          DEBUG_PRINTLN("\nreadConfig():");
          DEBUG_PRINT("\tAPI: ");
          DEBUG_PRINTLN(wm_wx_api);
          DEBUG_PRINT("\tLAT: ");
          DEBUG_PRINTLN(wm_wx_lat);
          DEBUG_PRINT("\tLON: ");
          DEBUG_PRINTLN(wm_wx_lon);
          DEBUG_PRINT("\tUNT: ");
          DEBUG_PRINTLN(wm_wx_unt);
          DEBUG_PRINT("\tDLC: ");
          DEBUG_PRINTLN(wm_wx_dlc);
          DEBUG_PRINT("\tALC: ");
          DEBUG_PRINTLN(wm_wx_alc);
          DEBUG_PRINT("\tDUR: ");
          DEBUG_PRINTLN(wm_wx_dur);
        }
        else
        {
          DEBUG_PRINTLN("Failed to load WFM config");
        }
        configFile.close();
      }
    }
  }
  else
  {
    DEBUG_PRINTLN("Failed to mount FS");
  }
} // readConfig()

// saves user parameters in LittleFS
void writeConfig()
{
  DEBUG_PRINTLN(F("Saving WFM config"));
  DynamicJsonDocument json(1024);
  // copy globals to json
  json["wx_api"] = wm_wx_api;
  json["wx_lat"] = wm_wx_lat;
  json["wx_lon"] = wm_wx_lon;
  json["wx_met"] = wm_wx_unt;
  json["wx_dlc"] = wm_wx_dlc;
  json["wx_alc"] = wm_wx_alc;
  json["wx_dur"] = wm_wx_dur;

  digitalClock = (strcmp(wm_wx_dlc, "D") == 0) ? true : false;
  analogClock = (strcmp(wm_wx_alc, "A") == 0) ? true : false;
  metricUnits = (strcmp(wm_wx_unt, "M") == 0) ? true : false;
  screenDuration = atoi(wm_wx_dur);

  DEBUG_PRINTLN("\nwriteConfig():");
  DEBUG_PRINT("\tAPI: ");
  DEBUG_PRINTLN(wm_wx_api);
  DEBUG_PRINT("\tLAT: ");
  DEBUG_PRINTLN(wm_wx_lat);
  DEBUG_PRINT("\tLON: ");
  DEBUG_PRINTLN(wm_wx_lon);
  DEBUG_PRINT("\tUNT: ");
  DEBUG_PRINTLN(wm_wx_unt);
  DEBUG_PRINT("\tDLC: ");
  DEBUG_PRINTLN(wm_wx_dlc);
  DEBUG_PRINT("\tALC: ");
  DEBUG_PRINTLN(wm_wx_alc);
  DEBUG_PRINT("\tDUR: ");
  DEBUG_PRINTLN(wm_wx_dur);

  File configFile = LittleFS.open(CONFIG_FILENAME, "w");
  if (!configFile)
  {
    DEBUG_PRINTLN("Failed to write WFM config");
  }

  serializeJson(json, Serial);
  serializeJson(json, configFile);
  configFile.close();
} // writeConfig()

/*
******************************************************
*********** DISPLAY TEXT FORMATTING ******************
******************************************************
*/
void displayFlushRight(String text, int rightColumn, int row, int textSize)
{
  int numChars = text.length();
  int widthText = textSize * (6 * numChars - 1);
  tft.setCursor(rightColumn - widthText, row);
  tft.setTextSize(textSize);
  tft.print(text);
} // displayFlushRight()

void displayCenter(String text, int centerColumn, int row, int textSize)
{
  int numChars = text.length();
  int widthText = textSize * (6 * numChars - 1);
  tft.setCursor(centerColumn - widthText / 2, row);
  tft.setTextSize(textSize);
  tft.print(text);
} // displayCenter()

/*
******************************************************
******************* SCREENS **************************
******************************************************
*/

/*
******************************************************
**************** Splash Screen ***********************
******************************************************
*/
void splashScreen()
{
  tft.fillScreen(BLUE);
  tft.setTextSize(2);
  tft.setTextColor(YELLOW);
  int topLine = 19;
  displayCenter("D1S-WBIT", SCREEN_W2, topLine, 2);
  displayCenter("Display", SCREEN_W2, topLine + 20, 2);
  displayCenter("by", SCREEN_W2, topLine + 40, 2);
  displayCenter("IoT Kits", SCREEN_W2, topLine + 60, 2);
  #ifdef TFT_MOD
  displayCenter("v" + String(FW_VERSION) + "V2", SCREEN_W2, topLine + 80, 2);
  #else
  displayCenter("v" + String(FW_VERSION), SCREEN_W2, topLine + 80, 2);
  #endif
  for (int i = 0; i < 4; i++)
  {
    tft.drawRoundRect(12 - 3 * i, 12 - 3 * i, SCREEN_W - 12, SCREEN_H - 12, 8, YELLOW);
  }
} // splashScreen()
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

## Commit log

2022-05-28 v1003
    Removed option for digital clock, add detect DHT11 failure to digital clock frame, removed code for analog clock
    [main.cpp]
2022-06-07 Add 3D stl files for case and cover
    [D1 Mini Display Case Rear.stl, D1 Mini Display Front Case.stl]
2022-06-08 Add case front v2
    [D1 Mini Display Front Case v2.stl]
2022-07-04 Update sensor pin info
2022-07-04 Move assembly photos inline
    Other updates and additions.
2022-07-04 Add column for wire color
2022-07-05 Record wire colors
2022-07-17 Add v3 case files
    [D1 Mini Display Front v3.stl, D1S Display Cover v3.stl]
2022-07-17 Add instructions for AHT10 sensor
